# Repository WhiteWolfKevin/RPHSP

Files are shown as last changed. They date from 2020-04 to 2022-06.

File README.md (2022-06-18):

# Raspberry Pi Home Security Project
This is a project I've been working on to use Raspberry Pis as a whole home security system.

# BUGS
**Known Bugs**
Currently, the python module spidev-3.5 does NOT work with pi-rc522. You must use spidev-3.4 in order for the RFID reader to work.

# Keypad Pi
## Raspberry Pi Pinout
```
          SD CARD
          [01][02]  LCD VCC
LCD SDA   [03][04]
LCD SCL   [05][06]  LCD GND
Keypad 4  [07][08]  Keypad 1
          [09][10]  Keypad 2
Keypad 5  [11][12]  Keypad 3
Keypad 6  [13][14]  
Keypad 7  [15][16]
RFID 3.3V [17][18]  RFID IRQ
RFID MOSI [19][20]  
RFID MISO [21][22]  RFID RST
RFID SCK  [23][24]  RFID SDA
RFID GND  [25][26]
          [27][28]
          [29][30]  Grn LED-
Red LED+  [31][32]  Grn LED+
          [33][34]  Red LED-
          [35][36]
          [37][38]
Buzzer -  [39][40]  Buzzer +
```
```
          SD CARD
          [3V3PWR][ 5VPWR]  LCD VCC
LCD SDA   [GPIO02][ 5VPWR]
LCD SCL   [GPIO03][  GRND]  LCD GND
Keypad 4  [GPIO04][GPIO14]  Keypad 1
          [  GRND][GPIO15]  Keypad 2
Keypad 5  [GPIO17][GPIO18]  Keypad 3
Keypad 6  [GPIO27][  GRND]  
Keypad 7  [GPIO22][GPIO23]
RFID 3.3V [3V3PWR][GPIO24]  RFID IRQ
RFID MOSI [GPIO10][  GRND]  
RFID MISO [GPIO09][GPIO25]  RFID RST
RFID SCK  [GPIO11][GPIO08]  RFID SDA
RFID GND  [  GRND][GPIO07]
          [ ID_SD][ ID_SC]
          [GPIO05][  GRND]  Grn LED-
Red LED+  [GPIO06][GPIO12]  Grn LED+
          [GPIO13][  GRND]  Red LED-
          [GPIO19][GPIO16]
          [GPIO26][GPIO20]
Buzzer -  [  GRND][GPIO21]  Buzzer +
```

# RFID Pinout
*Viewed from the back of the reader from left to right*
```
[                          ]
[                          ]
[                          ]
[                          ]
[                          ]
[                          ]
[                          ]
[                          ]
[                          ]
[                          ]
[ (1)(2)(3)(4)(5)(6)(7)(8) ]

  1    2    3    4    5     6     7    8
(VCC)(RST)(GND)(IRQ)(MISO)(MOSI)(SCK)(SDA)
```

# 12-Digit Keypad Configuration
```
[ 1 2 3 ]
[ 4 5 6 ]
[ 7 8 9 ]
[ * 0 # ]
```
```
Keypad Pinout
Pin 1 - Column 2 {2,5,8,0}
Pin 2 - Row 1 {1,2,3}
Pin 3 - Column 1 {1,4,7,*}
Pin 4 - Row 4 {*,0,#}
Pin 5 - Column 3 {3,6,9,#}
Pin 6 - Row 3 {7,8,9}
Pin 7 - Row 2 {4,5,6}
```
```
GPIO Pin Numbers (Left to right looking at front of keypad)
14,15,18,4,17,27,22
[Col 2] [Row 1] [Col 1] [Row 4] [Col 3] [Row 3] [Row 2]
ROW [15, 22, 27, 4]
COL [18, 14, 17]
```
```
* To adjust the key delay, go to this file and edit the "DEFAULT_KEY_DELAY" value
* Default value is 300
* A good value to set 150
/home/pi/.local/lib/python2.7/site-packages/pad4pi/rpi_gpio.py
```

# Required Packages
```
sudo apt update
sudo apt upgrade -y
sudo apt dist-upgrade -y
sudo apt install git -y
git clone https://github.com/kevbo423/RPHSP ~/RPHSP
sudo apt install i2c-tools -y
sudo apt install python-smbus -y
sudo apt install python-pip -y
sudo pip install spidev
sudo pip install pi-rc522
sudo pip install pad4pi
sudo pip install requests
sudo raspi-config
-Enable I2C
-Enable SPI

Detect LCD ID and edit i2c_driver.py
```

# LCD Display
**Identify LCD i2c address**
```
i2cdetect -y 1
Modify i2c_driver.py with this address
```

**Keypad I2C LCD Screen**\
Helpful Guide
https://howchoo.com/g/zwq2zwixotu/how-to-make-a-raspberry-pi-smart-alarm-clock

Dependencies
```
sudo apt-get install i2c-tools
sudo apt-get install python-smbus
i2cdetect -y 1
```

# MFRC522 RFID Reader
**RFID MFRC522 Info**\
Helpful Guide
https://github.com/ondryaso/pi-rc522

# Web Server Configuration
```
sudo apt install apache2
sudo apt install php-mysql
```

# Database Configuration
*NOTE:* Database being designed at `https://app.dbdesigner.net/`
Make the database accessible from the network.
```
Network Access: Add "bind_address=192.168.1.250" and "[mysqld] bind_address=192.168.1.250" to /etc/mysql/mariadb.cnf
```

Create the main database.
```
CREATE DATABASE rphsp;
```

Create the user of the database and give all privileges to that user.
```
CREATE USER 'rphsp'@'192.168.1.0/255.255.255.0';
```
```
GRANT ALL PRIVILEGES ON rphsp.* TO 'rphsp'@'192.168.1.0/255.255.255.0';
```

Create all of the tables.
```
CREATE TABLE sensors (
     gpio_pin INT(2) PRIMARY KEY,
     name VARCHAR(30),
     type VARCHAR(30)
);
```
```
CREATE TABLE alarms (
     id INT(2) PRIMARY KEY,
     name VARCHAR(30),
     status VARCHAR(15)
);
```
```
CREATE TABLE user_information (
     user_id int(4) AUTO_INCREMENT,
     first_name varchar(30) NOT NULL,
     last_name varchar(30) NOT NULL,
     date_added datetime NOT NULL DEFAULT CURRENT_TIMESTAMP,
     enabled bool NOT NULL DEFAULT 1,
     PRIMARY KEY (user_id)
);
```
```
CREATE TABLE rfid_cards (
     card_number char(10),
     user_id int(4),
     PRIMARY KEY (card_number),
     FOREIGN KEY (user_id) REFERENCES user_information(user_id)
);
```
```
CREATE TABLE pin_codes (
     pin_code int(6),
     user_id int(4),
     PRIMARY KEY (pin_code),
     FOREIGN KEY (user_id) REFERENCES user_information(user_id)
);
```
```
CREATE TABLE relays (
     relay_id int(4) AUTO_INCREMENT,
     relay_name varchar(30) NOT NULL,
     channels int (2) NOT NULL,
     PRIMARY KEY (relay_id)
);
```
```
CREATE TABLE relay_pins (
     relay_id int(4),
     relay_pin int(2),
     status char(3),
     PRIMARY KEY (relay_id, relay_pin),
     FOREIGN KEY (relay_id) REFERENCES relays(relay_id)
);
```

Test data inserts.
```
INSERT INTO sensors (gpio_pin, name, type) VALUES (16, "Front Door", "Door");
INSERT INTO sensors (gpio_pin, name, type) VALUES (20, "Garage Door", "Door");
INSERT INTO sensors (gpio_pin, name, type) VALUES (21, "Basement Door", "Door");
INSERT INTO sensors (gpio_pin, name, type) VALUES (26, "Living Room Window", "Window");
```

```
INSERT INTO user_information (first_name, last_name) VALUES ("John", "Smith");
INSERT INTO rfid_cards VALUES ("4a1a560f09", 1);
INSERT INTO pin_codes VALUES (111111, 1);
```

```
INSERT INTO relays (relay_name, channels) VALUES ("Test Relay", 4);
INSERT INTO relay_pins VALUES (1, 4, "Off");
INSERT INTO relay_pins VALUES (1, 17, "Off");
INSERT INTO relay_pins VALUES (1, 27, "Off");
INSERT INTO relay_pins VALUES (1, 22, "Off");
```

# REst API Stuff
All responses will have the form
```json
{
     "data": "Mixed type holding the content of the response",
     "message": "Description of what happened"
}
```

Subsequent response definitions will only detail the expected value of the 'data field'

# List all users
**Definition**
'GET /users'

**Response**
- '200 OK' on success

```json
[
     {
          "user_id": "0001",
          "first_name": "John",
          "last_name": "Smith",
          "date_added": "2020-04-14 19:56:32",
          "expiration_date": "2021-04-14 19:56:32",
          "enabled": "True",
          "pin_code": "111111",
          "rfid_card": "4a1a560f09"
     }
     {
          "user_id": "0002",
          "first_name": "Jane",
          "last_name": "Doe",
          "date_added": "2020-04-14 19:56:32",
          "expiration_date": "2021-04-14 19:56:32",
          "enabled": "True",
          "pin_code": "222222",
          "rfid_card": "4a1a560f09"
     }
]
```

# Register a new user
**Definition**
'POST /users'

**Arguments**
- '"first_name":string' The first name of the user
- '"last_name":string' The last name of the user
- '"expiration_date:"string' The expiration date of the user
- '"pin_code":number' The 6-digit pin code for the user
- '"rfid_card":string' The HEX code of the user's rfid card

**Response**
- '201 Created' on success

```json
{
     "user_id": "0001",
     "first_name": "John",
     "last_name": "Smith",
     "date_added": "2020-04-14 19:56:32",
     "expiration_date": "2021-04-14 19:56:32",
     "enabled": "True",
     "pin_code": "111111",
     "rfid_card": "4a1a560f09"
}
```

# Lookup user details
**Definition**
'GET /users/<user_id>'

**Response**

- '404 Not Found' If the user doesn't exist
- '200 OK' On success

```json
{
     "user_id": "0001",
     "first_name": "John",
     "last_name": "Smith",
     "date_added": "2020-04-14 19:56:32",
     "expiration_date": "2021-04-14 19:56:32",
     "enabled": "True",
     "pin_code": "111111",
     "rfid_card": "4a1a560f09"
}
```

# Delete a user
**Definition**
'DELETE /users/<user_id>'

**Response**

- '404 Not Found' If the user doesn't exist
- '204 No Content' On success

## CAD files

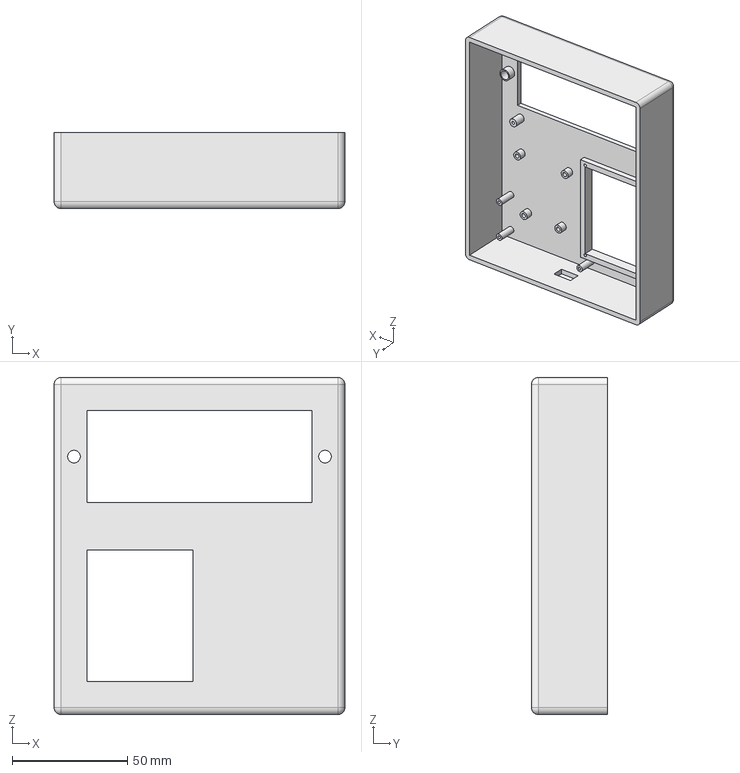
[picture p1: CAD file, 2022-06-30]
CAD_Files/Keypad/Keypad_Box.FCStd
126.0 x 33.0 x 146.0 mm

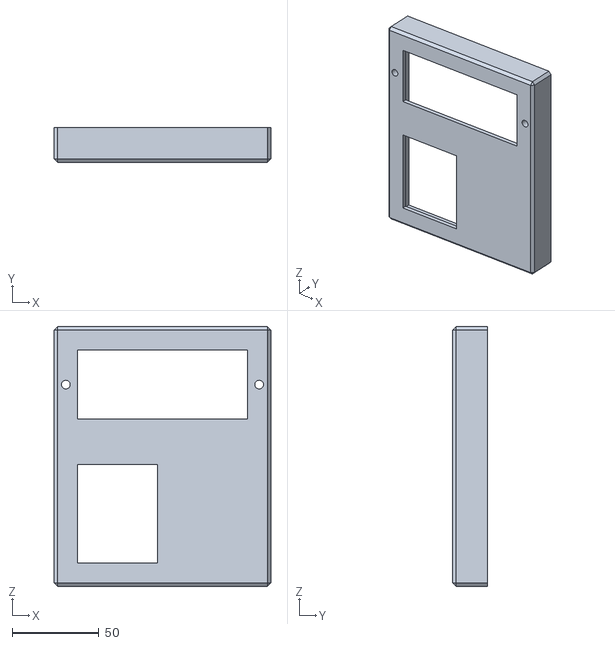
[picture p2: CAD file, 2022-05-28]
CAD_Files/Keypad/STLs/Keypad_Box-Mk_1.stl
125.0 x 20.0 x 150.0

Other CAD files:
CAD_Files/Keypad/STLs/Keypad_Box-Mk_3.stl
CAD_Files/Keypad/STLs/Keypad_Box-Mk_2.stl

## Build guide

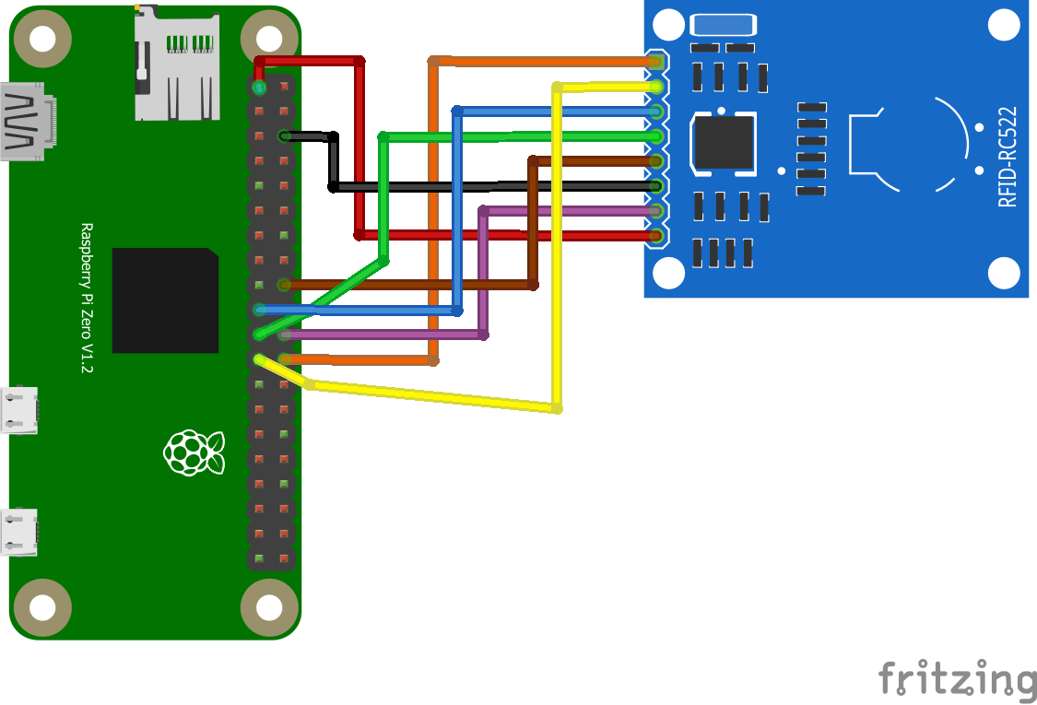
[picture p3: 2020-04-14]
Keypad_Files/MFRC522_Wiring.png

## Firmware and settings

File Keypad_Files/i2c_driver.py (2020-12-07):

import smbus
import time

# LCD Address
ADDRESS = 0x3f

# commands
LCD_CLEARDISPLAY = 0x01
LCD_RETURNHOME = 0x02
LCD_ENTRYMODESET = 0x04
LCD_DISPLAYCONTROL = 0x08
LCD_CURSORSHIFT = 0x10
LCD_FUNCTIONSET = 0x20
LCD_SETCGRAMADDR = 0x40
LCD_SETDDRAMADDR = 0x80

# flags for display entry mode
LCD_ENTRYRIGHT = 0x00
LCD_ENTRYLEFT = 0x02
LCD_ENTRYSHIFTINCREMENT = 0x01
LCD_ENTRYSHIFTDECREMENT = 0x00

# flags for display on/off control
LCD_DISPLAYON = 0x04
LCD_DISPLAYOFF = 0x00
LCD_CURSORON = 0x02
LCD_CURSOROFF = 0x00
LCD_BLINKON = 0x01
LCD_BLINKOFF = 0x00

# flags for display/cursor shift
LCD_DISPLAYMOVE = 0x08
LCD_CURSORMOVE = 0x00
LCD_MOVERIGHT = 0x04
LCD_MOVELEFT = 0x00

# flags for function set
LCD_8BITMODE = 0x10
LCD_4BITMODE = 0x00
LCD_2LINE = 0x08
LCD_1LINE = 0x00
LCD_5x10DOTS = 0x04
LCD_5x8DOTS = 0x00

# flags for backlight control
LCD_BACKLIGHT = 0x08
LCD_NOBACKLIGHT = 0x00

En = 0b00000100  # Enable bit
Rw = 0b00000010  # Read/Write bit
Rs = 0b00000001  # Register select bit


class I2CDevice:
    def __init__(self, addr, port=1):
        self.addr = addr
        self.bus = smbus.SMBus(port)

    def write_cmd(self, cmd):
        """Write a single command"""
        self.bus.write_byte(self.addr, cmd)
        time.sleep(0.0001)

    def write_cmd_arg(self, cmd, data):
        self.bus.write_byte_data(self.addr, cmd, data)
        time.sleep(0.0001)

    def write_block_data(self, cmd, data):
        """Write a block of data"""
        self.bus.write_block_data(self.addr, cmd, data)
        time.sleep(0.0001)

    def read(self):
        """Read a single byte"""
        return self.bus.read_byte(self.addr)

    def read_data(self, cmd):
        return self.bus.read_byte_data(self.addr, cmd)

    def read_block_data(self, cmd):
        """Read a block of data"""
        return self.bus.read_block_data(self.addr, cmd)


class LCD:
    def __init__(self, lock):
        """Initializes objects and the LCD"""
        self.lcd_device = I2CDevice(ADDRESS)

        self.lcd_write(0x03)
        self.lcd_write(0x03)
        self.lcd_write(0x03)
        self.lcd_write(0x02)

        self.lcd_write(
                LCD_FUNCTIONSET | LCD_2LINE | LCD_5x8DOTS | LCD_4BITMODE)
        self.lcd_write(LCD_DISPLAYCONTROL | LCD_DISPLAYON)
        self.lcd_write(LCD_CLEARDISPLAY)
        self.lcd_write(LCD_ENTRYMODESET | LCD_ENTRYLEFT)
        time.sleep(0.2)

        # Set the lock for the RPHSP
        self.lock = lock

    def lcd_strobe(self, data):
        """Clocks EN to latch command"""
        self.lcd_device.write_cmd(data | En | LCD_BACKLIGHT)
        time.sleep(.0005)
        self.lcd_device.write_cmd(((data & ~En) | LCD_BACKLIGHT))
        time.sleep(.0001)

    def lcd_write_four_bits(self, data):
        self.lcd_device.write_cmd(data | LCD_BACKLIGHT)
        self.lcd_strobe(data)

    def lcd_write(self, cmd, mode=0):
        """Write a command to lcd"""
        self.lcd_write_four_bits(mode | (cmd & 0xF0))
        self.lcd_write_four_bits(mode | ((cmd << 4) & 0xF0))

    def lcd_write_char(self, charvalue, mode=1):
        """
        Write a character to lcd (or character rom) 0x09: backlight
        | RS=DR< works!
        """
        self.lcd_write_four_bits(mode | (charvalue & 0xF0))
        self.lcd_write_four_bits(mode | ((charvalue << 4) & 0xF0))

    def lcd_display_string(self, string, line):
        """Put string function"""
        if line == 1:
            self.lcd_write(0x80)
        if line == 2:
            self.lcd_write(0xC0)
        if line == 3:
            self.lcd_write(0x94)
        if line == 4:
            self.lcd_write(0xD4)

        for char in string:
            self.lcd_write(ord(char), Rs)

    def lcd_clear(self):
        """Clear lcd and set to home"""
        self.lcd_write(LCD_CLEARDISPLAY)
        self.lcd_write(LCD_RETURNHOME)

    # REMOVED IN FAVOR OF BELOW backlight FUNCTION FOR RPHSP
    # def backlight(self, state):
    #     """define backlight on/off (lcd.backlight(1); off= lcd.backlight(0)
    #
    #     state: 1=on, 0=off
    #     """
    #     if state == 1:
    #         self.lcd_device.write_cmd(LCD_BACKLIGHT)
    #     elif state == 0:
    #         self.lcd_device.write_cmd(LCD_NOBACKLIGHT)

    def lcd_load_custom_chars(self, fontdata):
        """add custom characters (0 - 7)"""
        self.lcd_write(0x40)
        for char in fontdata:
            for line in char:
                self.lcd_write_char(line)

    def lcd_display_string_pos(self, string, line, pos):
        """define precise positioning (addition from the forum)"""
        if line == 1:
            pos_new = pos
        elif line == 2:
            pos_new = 0x40 + pos
        elif line == 3:
            pos_new = 0x14 + pos
        elif line == 4:
            pos_new = 0x54 + pos

        self.lcd_write(0x80 + pos_new)

        for char in string:
            self.lcd_write(ord(char), Rs)

    # RPHSP Custom Functions
    # Rewrite the entire given line with the given text
    def updateLCDScreen(self, text, line):
        self.lock.acquire()
        self.lcd_display_string(text, line)
        self.lock.release()

    # Write the given text at the given position on the given line
    def updateLCDScreenLine(self, text, line, position):
        self.lock.acquire()
        self.lcd_display_string_pos(text, line, position)
        self.lock.release()

    # Clear the LCD screen (Just a rename of the lcd_clear function above)
    def clearLCDScreen(self):
        self.lcd_clear()

    # Control the backlight (An adjusted fucnction that allows for text input)
    def backlight(self, status):
        if (str(status).lower() == "on"):
            self.lcd_device.write_cmd(LCD_BACKLIGHT)
        elif (str(status).lower() == "off"):
            self.lcd_device.write_cmd(LCD_NOBACKLIGHT)

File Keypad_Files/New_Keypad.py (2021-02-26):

#!/usr/bin/env python

# ==================================================================
# Imports
# ==================================================================

# Imports for system functions
import RPi.GPIO as GPIO
import os
import time
import threading

# Imports for LCD Screen
import i2c_driver

# Imports for Keypad
from pad4pi import rpi_gpio

# Imports for RFID
from pirc522 import RFID

# Imports for interacting with web interface
import requests

# ==================================================================
# Functions and Configurations
# ==================================================================

# Configure Keypad Buttons
KEYPAD = [
    [1, 2, 3],
    [4, 5, 6],
    [7, 8, 9],
    ["*", 0, "#"]
]

# Define pins used for Keypad, create variable for keypress counting, and create empty variable for keycode entry
ROW_PINS = [15, 22, 27, 4]
COL_PINS = [18, 14, 17]
keypressCounter = 0
userEntry = ""

# Variable to hold the duration of the backlight timer
backlightTimerDuration = 30

# Configure GPIO pins to use Broadcom numbering
GPIO.setmode(GPIO.BCM)

# ==================
# LED Functions
# ==================

# Configure the pins for LED feedback and turn them off to start
GPIO.setup(6,GPIO.OUT)
GPIO.setup(12,GPIO.OUT)
GPIO.output(6,0)
GPIO.output(12,0)

# Function for access granted LED feedback
def accessGrantedLED():
    GPIO.output(12,1)
    time.sleep(1)
    GPIO.output(12,0)

# Function for access denied LED feedback
def accessDeniedLED():
    GPIO.output(6,1)
    time.sleep(1)
    GPIO.output(6,0)

# Function for error LED feedback
def errorLED():
    for i in range(5):
        GPIO.output(6,1)
        time.sleep(0.2)
        GPIO.output(6,0)
        GPIO.output(12,1)
        time.sleep(0.2)
        GPIO.output(12,0)

# ==================
# Buzzer Functions
# ==================

# Configure the pins for the Buzzer output and turn it off to start
GPIO.setup(21,GPIO.OUT)
GPIO.output(21,0)

# Function for Buzzer Button Output
def buttonPushedBuzzer():
    GPIO.output(21,1)
    time.sleep(0.2)
    GPIO.output(21,0)

# Function for Buzzer Access Denied Output
def accessDeniedBuzzer():
    GPIO.output(21,1)
    time.sleep(1)
    GPIO.output(21,0)

# Function for Buzzer Alarm Output
def errorBuzzer():
    for i in range(5):
        GPIO.output(21,1)
        time.sleep(0.2)
        GPIO.output(21,0)
        time.sleep(0.2)

# ==================
# LCD Screen Functions
# ==================
def accessGrantedLCDDisplay():
    lcd.updateLCDScreen("Access Granted", 2)
    time.sleep(1)
    lcd.updateLCDScreen("                    ", 2)

def accessDeniedLCDDisplay():
    lcd.updateLCDScreen("Access Denied", 2)
    time.sleep(1)
    lcd.updateLCDScreen("                    ", 2)

# ==================
# Database Functions
# ==================
def getAlarmStatus():
    return requests.get("http://pibasestation/webinterface/alarm_status.php").content

# ==================
# Access Configurations
# ==================
def accessDenied():
    # Run the functions that correspond to an accessDenied event
    accessDeniedLCDDisplayRun = threading.Thread(target=accessDeniedLCDDisplay)
    accessDeniedLEDRun = threading.Thread(target=accessDeniedLED)
    accessDeniedBuzzerRun = threading.Thread(target=accessDeniedBuzzer)
    accessDeniedLCDDisplayRun.start()
    accessDeniedLEDRun.start()
    accessDeniedBuzzerRun.start()
    # Sleep for 1 second while the accessDenied function finish
    time.sleep(1)

def accessGranted(user_entry):
    accessGrantedLED()

    alarmStatus = getAlarmStatus();

    if (alarmStatus == "DISARMED"):
        print("This is where I need to ARM the system")
        i = 5
        while (i > 0):
            # Make the buzzer sound
            buttonPushedBuzzerSound = threading.Thread(target=buttonPushedBuzzer)
            buttonPushedBuzzerSound.start()

            # Reset the backlight timer so it doesn't go out
            backlightTimer = backlightTimerDuration

            # Display the time left until the system is armed
            print("Time to arm: " + str(i))
            lcd.updateLCDScreen("Arming in: " + str(i), 2)
            i = i - 1
            time.sleep(1)

        # Arm the security system
        if (len(user_entry) == 6):
            requests.get("http://pibasestation/webinterface/keypad_auth.php?pin_code=" + user_entry).content
        elif (len(user_entry) == 10):
            requests.get("http://pibasestation/webinterface/keypad_auth.php?rfid_card_number=" + user_entry).content
        else:
            print("Error trying to arm")


        lcd.updateLCDScreen("SYSTEM IS ARMED", 2)
        time.sleep(2)
        lcd.updateLCDScreen("                    ", 2)
    elif (alarmStatus == "ARMED"):
        print("This is where I need to DISARM the system")
        # Disarm the security system
        if (len(user_entry) == 6):
            requests.get("http://pibasestation/webinterface/keypad_auth.php?pin_code=" + user_entry).content
        elif (len(user_entry) == 10):
            requests.get("http://pibasestation/webinterface/keypad_auth.php?rfid_card_number=" + user_entry).content
        else:
            print("Error trying to arm")
    else:
        print("Alarm Status: " + alarmStatus)
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

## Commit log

2019-10-28 Beginning arm/disarm system
2019-11-12 Created Security_System.py to experiment with arming/disarming system with threading
2019-11-12 Added thread args
2019-11-12 Removed thread arguments
2019-11-12 Removed Unused variables and moved securityCompromised variable inside of thread
2020-03-05 Moved Magnetic_Sensor.py contents to Home_Security_System.py
2020-03-06 Working - Starting work on arm/disarm system
2020-03-06 Testing with Threading and Arm/Disarm System
2020-03-23 Added Red/Green LED functionality
2020-03-24 Added locking mechanism for writing to LCD display. This took care of the bug with simultaneous writes to the LCD display getting corrupted
    [Home_Security_System.py, Keypad.py]
2020-04-04 Started on a web interface for the Security System dashboard. Also added lines in Home_Security_System.py to set the status of the window/door sensors.
2020-04-10 Configured sensors in Home_Security_System.py to use MariaDB
2020-04-14 Added picture of wiring diagram for MFRC522 RFID reader that allows for interrupts which drastically lowers the CPU usage
2020-04-14 Added a couple test scripots and started working on RFID tests
2020-04-16 Adjusted backlight timer function. Added sleep to reduce CPU overhead.
2020-04-16 Adjusted RFID settings to use BCM mode instead of board mode. Started on RFID auth in Keypad.py
2020-04-16 Pin code and RFID card authnetication is fully functional. MariaDB usage in Keypad.py has been removed in favor of PHP GET requests.
2020-04-18 Created special functions for LCD screen within i2c_driver.py in order to reduce code in Keypad.py
2020-04-18 Added error checking for Keypay.py
    [Keypad.py]
2020-04-28 Started some work with a 4 channel relay
2020-07-03 Added support for dynamic display of relay information from database to web interface
2020-11-30 Testing out buzzer implementation on keypad
    [Keypad.py]
2020-11-30 Added buzzer sound to RFID reader
    [Keypad.py]
2020-12-01 Switched from threading to subprocess for buzzer sound testing
    [Keypad.py]
2020-12-01 Switched back to threading for buzzer sound testing
    [Keypad.py]
2020-12-01 Corrected threading issues with the Buzzer via a stackoverflow question answer
    [Keypad.py]
2020-12-07 Modified working environment to avoid using git commit/pushes during code modification and testing. Modified directory structure for better organization.
    [Home_Security_System.py, Keypad.py, i2c_driver.py]
2020-12-07 Created file for database configuration and modified README.md
    [Configuration.txt]
2020-12-07 Formatted database configuration file and added the data to the README
    [Configuration.txt]
2020-12-08 Created New_Keypad.py script in order to rework Keypad program and implement 30 second delay
    [New_Keypad.py]
2021-02-19 Added Keypad Pinout ASCII Diagram to README. Also adjust a few pin locations for better layout.
2021-02-20 Corrected issue with incorrect keypad pinout in README and Keypad scripts
    [New_Keypad.py]
2021-02-26 Fixed issue with RFID reader on new keypad and started work on basestation
    [Home_Security_System.py]
2021-02-26 Started work on logging pin codes and rfid cards. Also added a feature in the keypad to auto clear the user input when the backlight shuts off.
2021-02-26 Corrected issue with log file overwriting rather than appending.
    [New_Keypad.py]
2022-05-28 Added first iteration of CAD_Files
    [Keypad_Box-Mk_I.stl, Keypad_Box.FCStd]
2022-05-30 Adjusted names of body contents and removed unnecessary keypad frame item
    [Keypad_Box.FCStd]
2022-06-18 Adjusted some things in the CAD file and printed Mk2 of the Keypad
    [Keypad_Box-Mk_1.stl, Keypad_Box-Mk_2.stl, Keypad_Box.FCStd]
2022-06-30 Created the Mark 3 .stl with additional changes
    [Keypad_Box-Mk_3.stl, Keypad_Box.FCStd]
